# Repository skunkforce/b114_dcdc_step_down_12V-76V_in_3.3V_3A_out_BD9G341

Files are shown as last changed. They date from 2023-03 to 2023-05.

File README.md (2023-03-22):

# edgy_board number b114
This design is part of the [edgy board project](https://github.com/skunkforce/edgy_boards). It provides a 3A 3.3V switching step-down regulator with a wide input voltage range. 



# getting started
This repository uses submodules. After cloning use the command 

```$ git submodule update --init --recursive```

to pull the submodules before opening the project with kicad. 

# Tests
Tests can be found in [TESTS.md](TESTS.md)

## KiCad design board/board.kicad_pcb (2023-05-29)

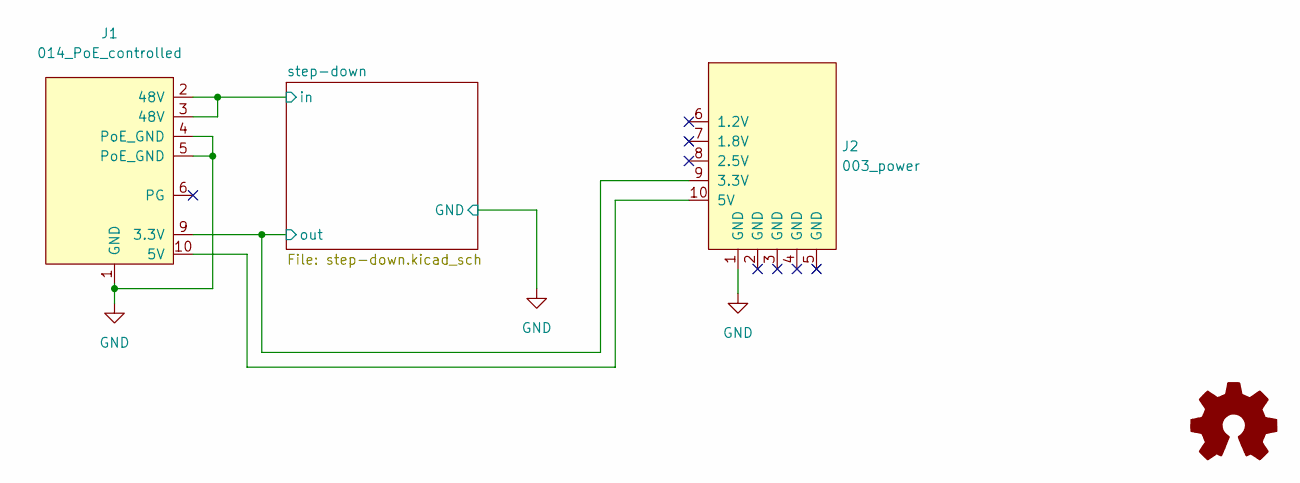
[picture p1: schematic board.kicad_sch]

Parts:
J1: 014_PoE_controlled; on_edge_2x05_device
J2: 003_power; on_edge_2x05_host
LOGO1: Logo_Open_Hardware_Small; OSHW-Symbol_6.7x6mm_SilkScreen

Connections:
/step-down/in: J1.2 (48V), J1.3 (48V); also elsewhere on the board
/step-down/out: J1.9 (3.3V), J2.9 (3.3V); also elsewhere on the board
GND: J1.1 (GND), J1.4 (PoE_GND), J1.5 (PoE_GND), J2.1 (GND); also elsewhere on the board
unnamed: J1.10 (5V), J2.10 (5V)

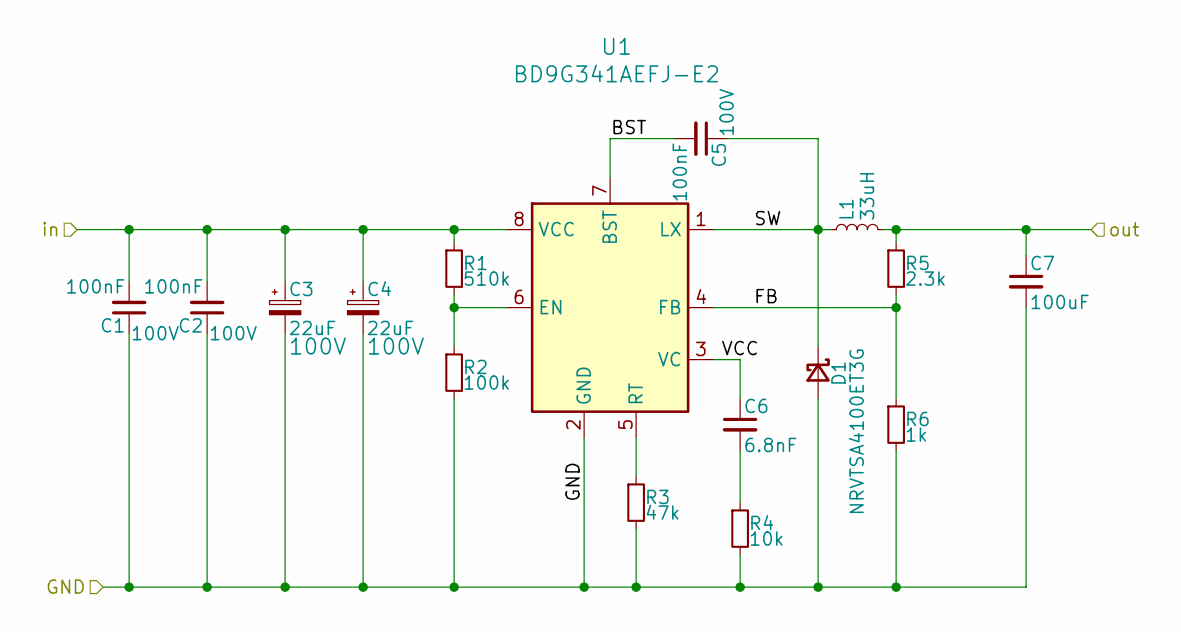
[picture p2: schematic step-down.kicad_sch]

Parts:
C1, C2, C5: 100nF; C_0603_1608Metric; Voltage 100V; Digi-Key_PN 1276-6807-1-ND
C3, C4: 22uF; CP_Elec_8x10; Voltage 100V; MPN 865080853006
C6: 6.8nF; C_0603_1608Metric; Voltage 6.3V; Digi-Key_PN 1276-1185-1-ND‎
C7: 100uF; C_1210_3225Metric; Voltage 6.3V; MPN 885012109004; Digi-Key_PN 732-7375-1-ND
D1: NRVTSA4100ET3G; D_SMA; MPN NRVTSA4100ET3G; Digi-Key_PN NRVTSA4100ET3GOSCT-ND
L1: 33uH; L_Bourns_SRR1210A; MPN 7447714330
R1: 510k; R_0603_1608Metric; MPN RMCF0603JT510K‎; Digi-Key_PN ‎RMCF0603JT510KCT-ND‎
R2: 100k; R_0603_1608Metric
R3: 47k; R_0603_1608Metric
R4: 10k; R_0603_1608Metric
R5: 2.3k; R_0603_1608Metric
R6: 1k; R_0603_1608Metric
U1: BD9G341AEFJ-E2; SOIC-8-1EP_3.9x4.9mm_P1.27mm_EP2.29x3mm_ThermalVias

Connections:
/step-down/in: C1.2, C2.2, C3.1, C4.1, R1.1, U1.8 (VCC); also elsewhere on the board
/step-down/out: C7.1, L1.2, R5.1; also elsewhere on the board
GND: C1.1, C2.1, C3.2, C4.2, C7.2, D1.2 (A), R2.2, R3.2, R4.2, R6.2, U1.2 (GND), U1.9 (GND); also elsewhere on the board
unnamed: C5.1, D1.1 (K), L1.1, U1.1 (LX)
unnamed: C5.2, U1.7 (BST)
unnamed: C6.1, U1.3 (VC)
unnamed: C6.2, R4.1
unnamed: R1.2, R2.1, U1.6 (EN)
unnamed: R3.1, U1.5 (RT)
unnamed: R5.2, R6.1, U1.4 (FB)

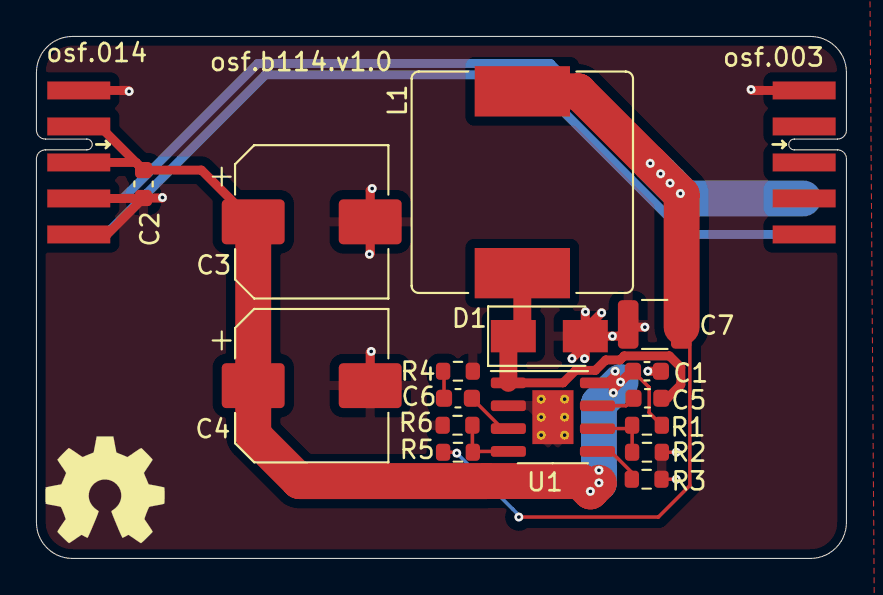
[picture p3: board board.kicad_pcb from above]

Board: 2 copper layers, 45.0 x 29.0 mm, 19 parts (0 on the bottom side), 11 nets.

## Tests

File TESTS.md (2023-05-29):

# load test
## setup
Connected 48V to the input side and a variable resistor to the output side. Measured the voltage of the output side.
## results
|voltage|load|
|---|---|
| 3.3v | 100mA
| 3.3v | 1A
| 3.2v | 2A
| 3.2v | 3A
| 3.1v | 4A
